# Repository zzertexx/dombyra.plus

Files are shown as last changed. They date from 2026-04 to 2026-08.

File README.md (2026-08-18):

# Dombyra Plus
Simple device to teach playing on Dombyra!


## Description
Have you ever wanted to learn playing Dombyra at home?
If yes, then you absolutely looked resources to learn, and what you found was some videos that shows you how they play, while you need to everytime find out which notes is being pressed.

I had exact same problem, so I built this!

This device is solution for it. First hardware addon for Dombyra.

Using bunch of SK6812 LEDs on Dombyra's neck, it will show you which notes need to be pressed right now and after.
By ESP32 and INMP441 mic, it will be controlled by local Website to choose notes and continue showing notes.

## Features
* Wi-Fi website to choose kuis
* 18 LEDs per string with two color mod for Up/Down play
* Battery charge system for autonomuos play
* Comfortable case to play
* Volume spike detector to continue play

## Firmware
* Firmware was written on Arduino IDE
* Currently it has Erkem-Ai
* Needed libraries: FastLED.h, i2s.h(core), WiFi.h(core), WebServer.h(core)

## Attachment
To make sure cases won't move, I added attachment legs for **LED case** and also usage of nylon tape for **microphone case** so you can remove device whenever you want

## How to actually use it?
1) Assemble PCB into Case
2) Use nylon to attach microphone case
3) Compile code into ESP32
4) Place PCBs on dombyra and connect both using **4-pin JST XH2.54** and specialized pins
5) Charge battery and start it
6) Connect to ESP32's Wi-Fi and enter http://192.168.4.1
7) Choose the kui that you wanna learn and enjoy the process!

## Bill of Materials

| Component | Quantity |
|---|---|
| ESP32 DevKit v1 | 1 |
| SK6812 LEDs | 38 |
| INMP441 module | 1 |
| Li-Po Battery + 2 pin header 2mm | 1 |
| USB-C Receptacle only 6 pin | 1 |
| TP4056 module | 1 |
| MT3608 module | 1 |
| M2 screws | 14 |
| M3 screws | 4 |
| 4 pin Connector Sockets - Angled | 1 |
| 4 pin Connector Sockets - Vertical | 1 |
| NTC 10k | 1 |
| Unpolarized capacitors(THT) 10uF & 22uF | 2 each |
| Inductor 4.7uH | 1 |
| Diode | 2 LED and 1 Schottky |
| Resistors | 110k; 15k; 330 x2; 68k; 2.4k; 1k; 0.4; 5k1 x2 |
| 4-pin JST XH2.54 | 1 |
| Nylon Tape | 1 |

## PCB & Schematics
Designed on KiCad 10.0

It consists of 2 PCBs. One on neck for LEDs and second one for Battery, Microphone and MCU. They are connected using 4-pin JST wires for GND, 5V and 2 data channels. 






## Images of cases
dombyra_case
3D Case2
3D Case1

## Demo 

https://youtu.be/3Eh5J_6kmjc

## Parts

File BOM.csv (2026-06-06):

Name | Quantity | Price | Link
SK6812 5050 | 38 | 6.33$/50pcs | https://aliexpress.ru/item/33015141472.html?sku_id=67232448537
4 pin Connector Sockets - angled | 1 | 0.76$/10pcs | https://aliexpress.ru/item/1005008048770666.html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
4 pin Connector Sockets - vertical | 1 | 0.64$/40pcs | https://aliexpress.ru/item/1005008048770666.html?mixer_rcmd_bucket_id=eb9dde40e7725560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
INMP441 module | 1 | 0.84$ | https://aliexpress.ru/item/1005004862555297.html?sku_id=12000030790772841
Li Po 1000 mAh | 1 | 5.82$ | https://aliexpress.ru/item/1005003380188983.html?sku_id=12000032368701982
2-Pin Header 2mm | 1 | 0.31$ | https://aliexpress.ru/item/1005004613948731.html?sku_id=12000029835450870
USB-C Receptacle only 6 pin | 1 | 0.93$ | https://aliexpress.ru/item/1005008515699009.html?sku_id=12000045521870266
ESP32 DevKit v1 | 1 | 3.68$ | https://aliexpress.ru/item/1005008819591380.html?sku_id=12000052999823660
TP4056 | 1 | 0.2$ | https://aliexpress.ru/item/1005001848329482.html?sku_id=12000046271485575
NTC 10k | 1 | 0.53$ / 10pcs | https://aliexpress.ru/item/1005004726168052.html?sku_id=12000056723062683
Unpolarized capacitor(THT) 10uF | 2 | 0.97$ / 40pcs | https://aliexpress.ru/item/1005011811368397.html?sku_id=12000056639843396
Unpolarized capacitor(THT) 22uF | 2 | 0.97$ / 40pcs | https://aliexpress.ru/item/1005011811368397.html?sku_id=12000056639843396
MT3608 | 1 | 1.38$ / 10pcs | https://aliexpress.ru/item/1005008853748359.html?sku_id=12000046953414150
Inductor 4.7uH | 1 | 0.54$ / 10pcs | https://aliexpress.ru/item/1005001705755960.html?sku_id=12000017231427125
LED Diode | 2 | 0.78$ / 60 pcs | https://aliexpress.ru/item/1005006462860778.html?sku_id=12000037284612047
Schottky diode | 1 | 0.88$ / 50pcs | https://aliexpress.ru/item/1005005913997312.html?sku_id=12000034823544465
Resistor 110k | 1 | 0.4$ / 100pcs | https://aliexpress.ru/item/1005005305821597.html?sku_id=12000032565737692
Resistor 15K | 1 | 0.46$ / 100pcs | https://aliexpress.ru/item/1005010583226050.html?mixer_rcmd_bucket_id=eb9dde40e7725560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
Resistor 330 | 2 | 0.46$ / 100pcs | https://aliexpress.ru/item/1005010583226050.html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
Resistor 68k | 1 | 0.46$ / 100pcs | https://aliexpress.ru/item/1005010583226050.html?mixer_rcmd_bucket_id=eb9dde40e7725560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
Resistor 2.4k | 1 | 0.46$ / 100pcs | https://aliexpress.ru/item/1005010583226050.html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
Resistor 1k | 1 | 0.46$ / 100pcs | https://aliexpress.ru/item/1005010583226050.html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
Resistor 0.4 | 1 | 0.46$ / 100pcs | https://aliexpress.ru/item/1005010583226050.html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
Resistor 5.1k | 2 | 0.46$ / 100pcs | https://aliexpress.ru/item/1005010583226050.html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
4-pin JST XH2.54 | 1 | 1.12$ | https://aliexpress.ru/item/1005004837211340.html?sku_id=12000030681544733
Nylon Tape | 1 | 0.87$ | https://aliexpress.ru/item/1005004816765023.html?sku_id=12000030600334971
Effective Sum |  | 19.5$/pc
Sum |  | 31$

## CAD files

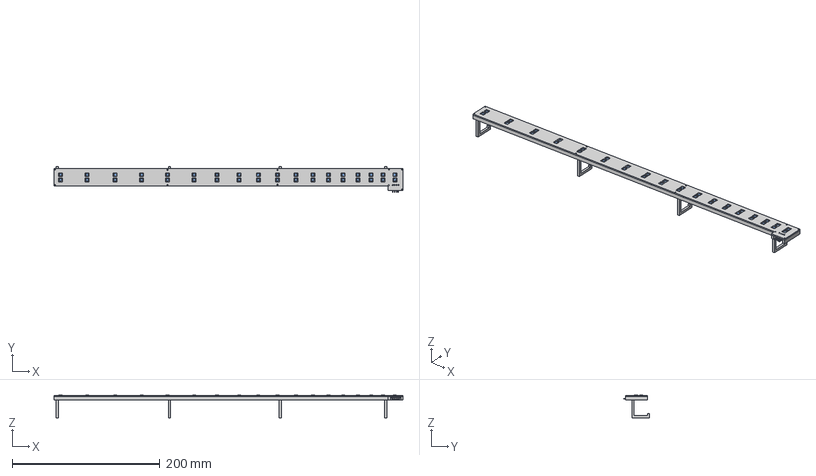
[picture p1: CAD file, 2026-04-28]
CAD/dombyra_case.step
472.9 x 35.2 x 30.6 mm

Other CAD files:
CAD/dombyra_case.f3z

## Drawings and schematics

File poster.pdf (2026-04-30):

# Dombyra+

# SK6812 LEDs going to

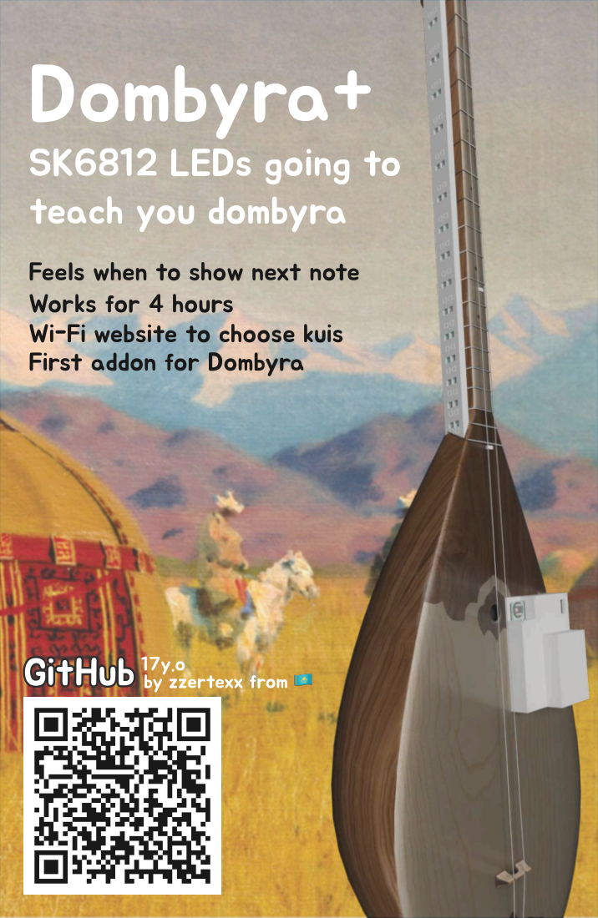
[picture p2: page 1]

teach you dombyra

Feels when to show next note
Works for 4 hours
Wi-Fi website to choose kuis
First addon for Dombyra

GitHub ¹⁷y.o by zzertexx from 🇰🇿

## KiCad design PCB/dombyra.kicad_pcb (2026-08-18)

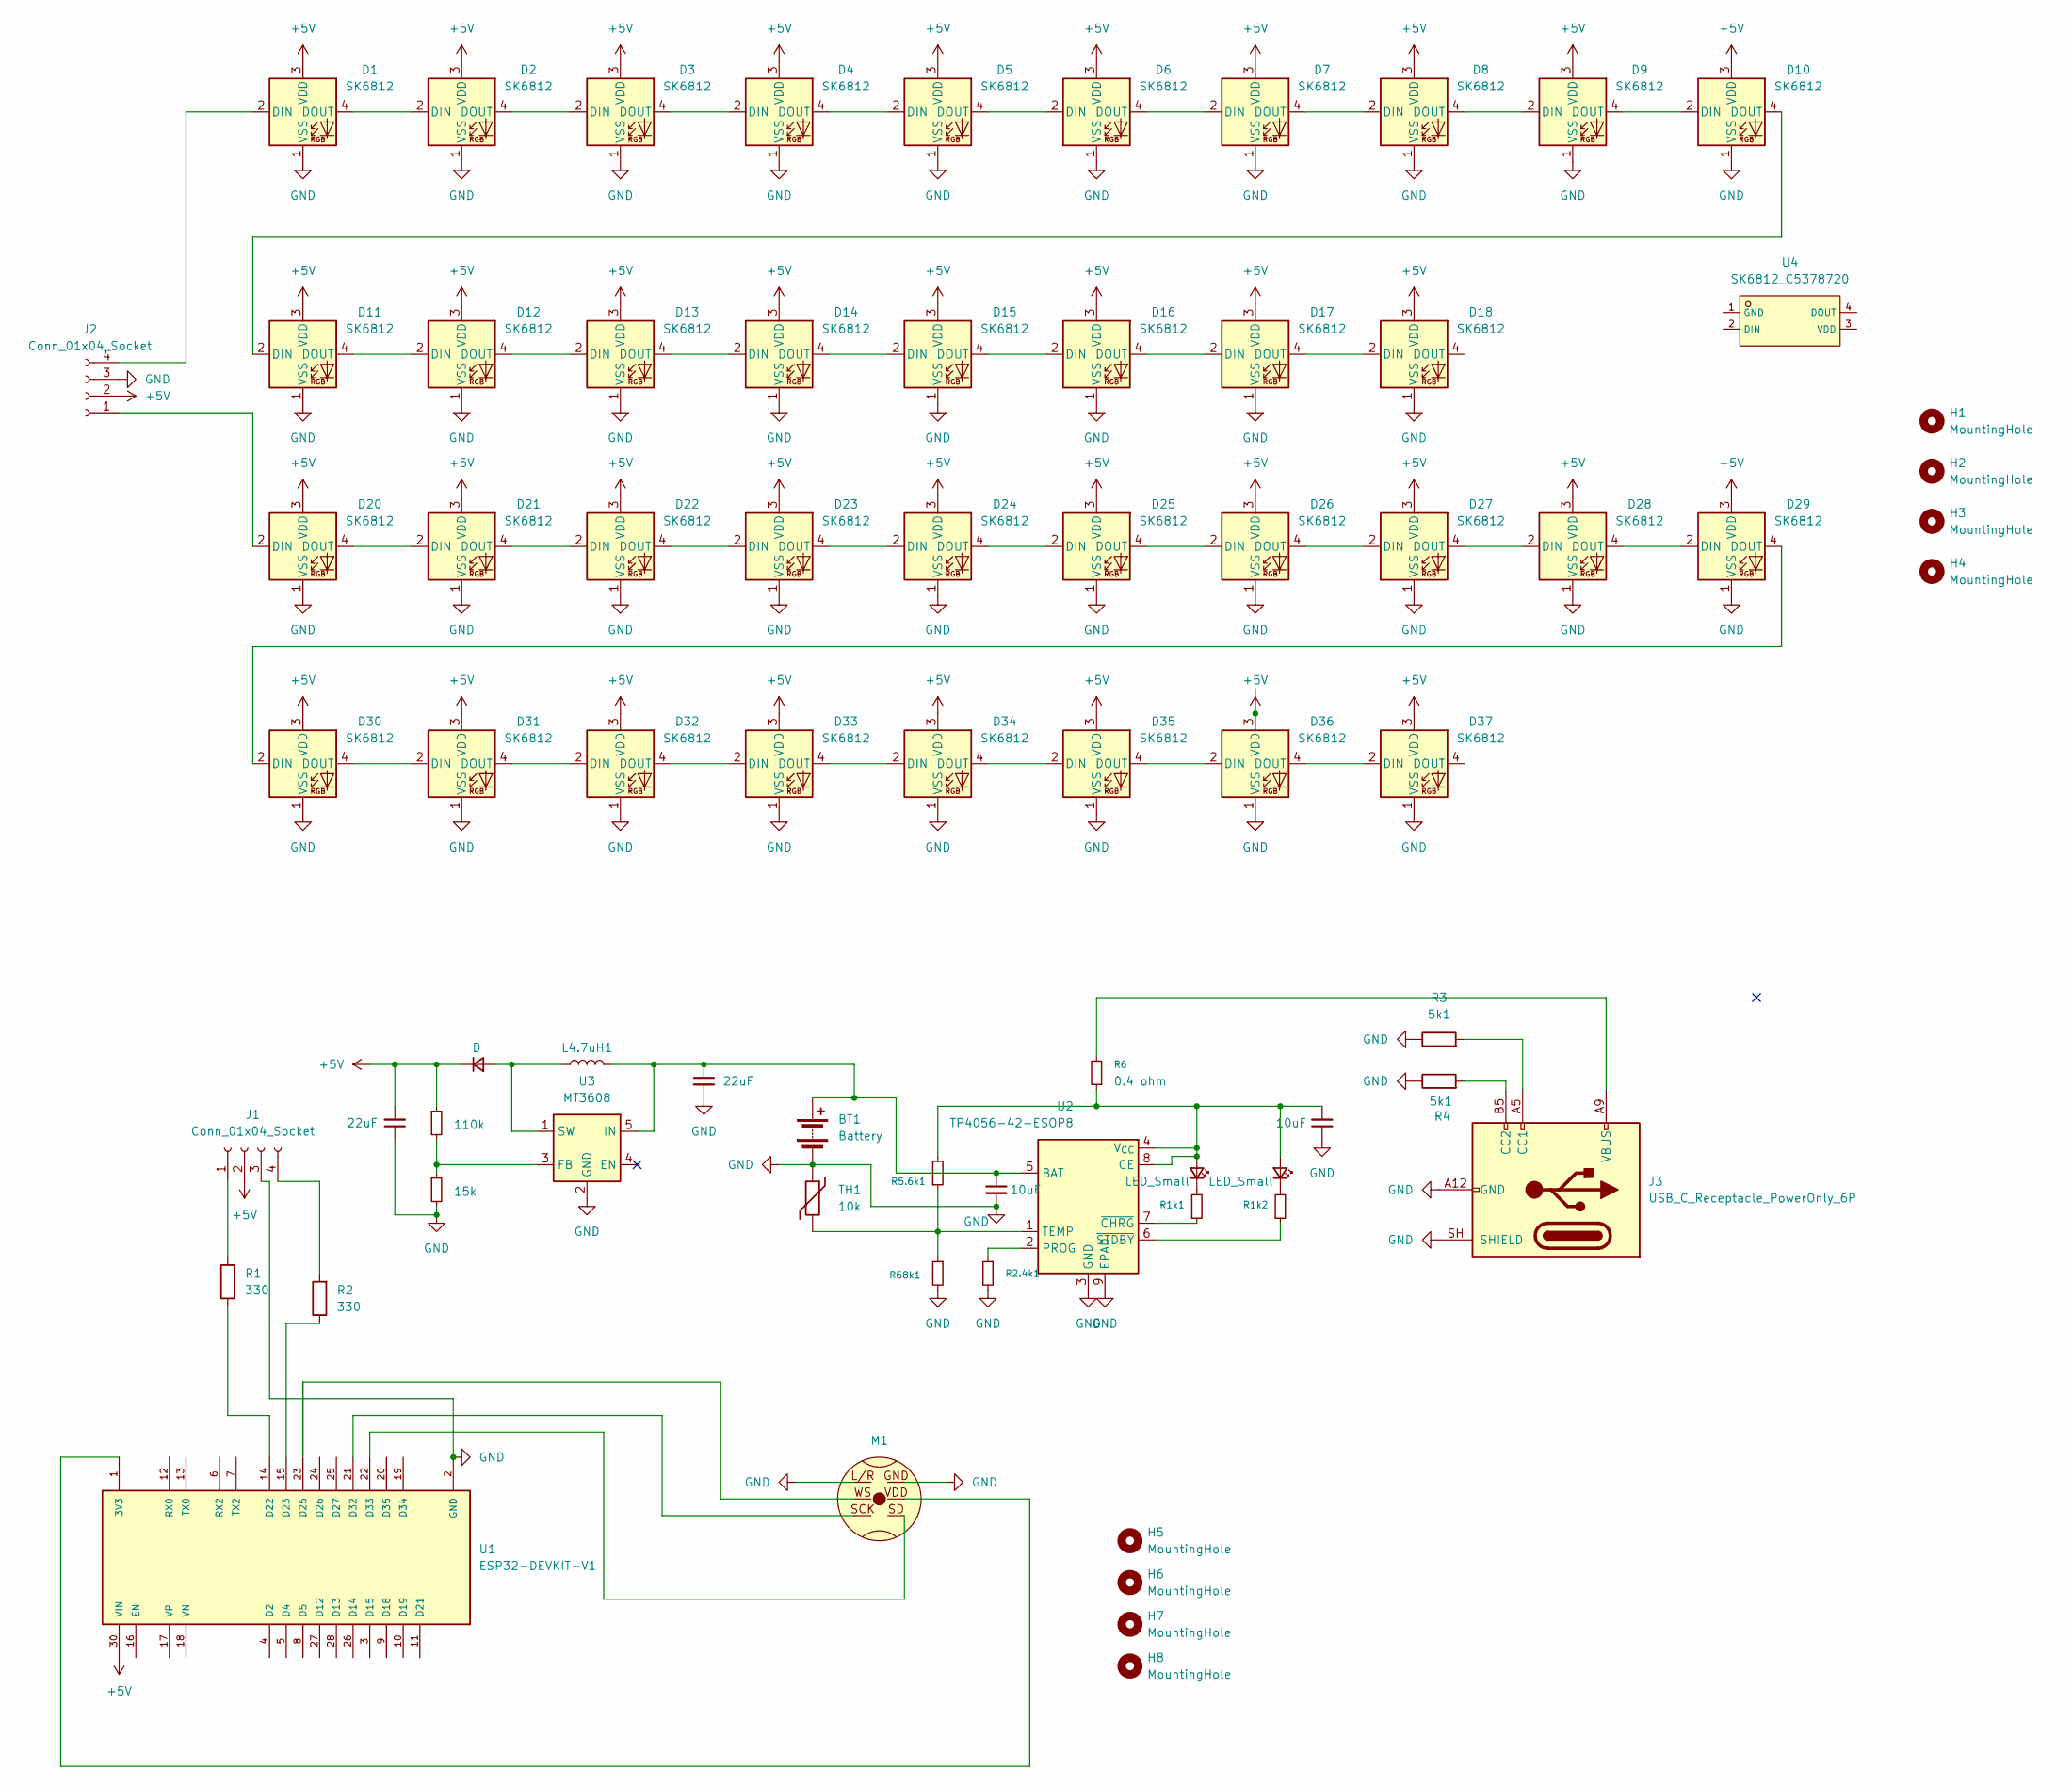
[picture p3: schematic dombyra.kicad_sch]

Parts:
BT1: Battery; PinHeader_1x02_P2.54mm_Vertical
C1, C2: 10uF; C_0805_2012Metric
C3, C4: 22uF; C_1206_3216Metric
D1, D2, D3, D4, D5, D6, D7, D8, D9, D10, D11, D12, D13, D14, D15, D16, D17, D18, D20, D21, D22, D23, D24, D25, D26, D27, D28, D29, D30, D31, D32, D33, D34, D35, D36, D37: SK6812; LED_SK6812_PLCC4_5.0x5.0mm_P3.2mm
D39: LED_Small; LED_D3.0mm
D40: LED_Small; LED_D5.0mm
D41: D; SMA_L4.3-W2.6-LS5.2-RD
H1, H2, H3, H4: MountingHole; MountingHole_3.2mm_M3
H5, H6, H7, H8: MountingHole; MountingHole_2.2mm_M2
J1: Conn_01x04_Socket; PinHeader_1x04_P2.54mm_Vertical_SMD_Pin1Left
J2: Conn_01x04_Socket; PinHeader_1x04_P2.54mm_Horizontal
J3: USB_C_Receptacle_PowerOnly_6P; USB_C_Receptacle_GCT_USB4135-GF-A_6P_TopMnt_Horizontal
L4.7uH1: L; L_1812_4532Metric
M1: INMP441
R1, R2: 330; R_0402_1005Metric
R1k1, R1k2: R_Small; R_0805_2012Metric
R2.4k1: R_Small; R_Axial_DIN0204_L3.6mm_D1.6mm_P1.90mm_Vertical
R3, R4: 5k1; R_0603_1608Metric
R5.6k1, R68k1: R_Small; R_0603_1608Metric
R6: 0.4 ohm; R_Axial_DIN0204_L3.6mm_D1.6mm_P1.90mm_Vertical
R9: 15k; R_0402_1005Metric
R10: 110k; R_0603_1608Metric
TH1: 10k; PinHeader_2x01_P2.00mm_Vertical
U1: ESP32-DEVKIT-V1; MODULE_ESP32_DEVKIT_V1; PARTREV N/A
U2: TP4056-42-ESOP8; SOIC-8-1EP_3.9x4.9mm_P1.27mm_EP2.41x3.3mm_ThermalVias
U3: MT3608; SOT-23-6
U4: SK6812_C5378720; LED-SMD_4P-L5.4-W5.0_SK6812; LCSC C5378720

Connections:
+5V: C3.2, D1.3 (VDD), D2.3 (VDD), D3.3 (VDD), D4.3 (VDD), D5.3 (VDD), D6.3 (VDD), D7.3 (VDD), D8.3 (VDD), D9.3 (VDD), D10.3 (VDD), D11.3 (VDD), D12.3 (VDD), D13.3 (VDD), D14.3 (VDD), D15.3 (VDD), D16.3 (VDD), D17.3 (VDD), D18.3 (VDD), D20.3 (VDD), D21.3 (VDD), D22.3 (VDD), D23.3 (VDD), D24.3 (VDD), D25.3 (VDD), D26.3 (VDD), D27.3 (VDD), D28.3 (VDD), D29.3 (VDD), D30.3 (VDD), D31.3 (VDD), D32.3 (VDD), D33.3 (VDD), D34.3 (VDD), D35.3 (VDD), D36.3 (VDD), D37.3 (VDD), D41.1 (K), J1.2, J2.2, R10.1, U1.30 (VIN)
GND: BT1.2 (-), C1.2, C2.1, C3.1, C4.2, D1.1 (VSS), D2.1 (VSS), D3.1 (VSS), D4.1 (VSS), D5.1 (VSS), D6.1 (VSS), D7.1 (VSS), D8.1 (VSS), D9.1 (VSS), D10.1 (VSS), D11.1 (VSS), D12.1 (VSS), D13.1 (VSS), D14.1 (VSS), D15.1 (VSS), D16.1 (VSS), D17.1 (VSS), D18.1 (VSS), D20.1 (VSS), D21.1 (VSS), D22.1 (VSS), D23.1 (VSS), D24.1 (VSS), D25.1 (VSS), D26.1 (VSS), D27.1 (VSS), D28.1 (VSS), D29.1 (VSS), D30.1 (VSS), D31.1 (VSS), D32.1 (VSS), D33.1 (VSS), D34.1 (VSS), D35.1 (VSS), D36.1 (VSS), D37.1 (VSS), J1.3, J2.3, J3.A12 (GND), J3.B12 (GND), J3.SH (SHIELD), M1.GND, M1.L/R, R2.4k1.2, R3.1, R4.1, R9.2, R68k1.2, TH1.1, U1.2 (GND), U1.29 (GND), U2.3 (GND), U2.9 (EPAD), U3.2 (GND)
unnamed: BT1.1 (+), C1.1, C4.1, L4.7uH1.2, U2.5 (BAT), U3.5 (IN)
unnamed: D1.2 (DIN), J2.4
unnamed: D1.4 (DOUT), D2.2 (DIN)
unnamed: D2.4 (DOUT), D3.2 (DIN)
unnamed: D3.4 (DOUT), D4.2 (DIN)
unnamed: D4.4 (DOUT), D5.2 (DIN)
unnamed: D5.4 (DOUT), D6.2 (DIN)
unnamed: D6.4 (DOUT), D7.2 (DIN)
unnamed: D7.4 (DOUT), D8.2 (DIN)
unnamed: D8.4 (DOUT), D9.2 (DIN)
unnamed: D9.4 (DOUT), D10.2 (DIN)
unnamed: D10.4 (DOUT), D11.2 (DIN)
unnamed: D11.4 (DOUT), D12.2 (DIN)
unnamed: D12.4 (DOUT), D13.2 (DIN)
unnamed: D13.4 (DOUT), D14.2 (DIN)
unnamed: D14.4 (DOUT), D15.2 (DIN)
unnamed: D15.4 (DOUT), D16.2 (DIN)
unnamed: D16.4 (DOUT), D17.2 (DIN)
unnamed: D17.4 (DOUT), D18.2 (DIN)
unnamed: D20.2 (DIN), J2.1
unnamed: D20.4 (DOUT), D21.2 (DIN)
unnamed: D21.4 (DOUT), D22.2 (DIN)
unnamed: D22.4 (DOUT), D23.2 (DIN)
unnamed: D23.4 (DOUT), D24.2 (DIN)
unnamed: D24.4 (DOUT), D25.2 (DIN)
unnamed: D25.4 (DOUT), D26.2 (DIN)
unnamed: D26.4 (DOUT), D27.2 (DIN)
unnamed: D27.4 (DOUT), D28.2 (DIN)
unnamed: D28.4 (DOUT), D29.2 (DIN)
unnamed: D29.4 (DOUT), D30.2 (DIN)
unnamed: D30.4 (DOUT), D31.2 (DIN)
unnamed: D31.4 (DOUT), D32.2 (DIN)
unnamed: D32.4 (DOUT), D33.2 (DIN)
unnamed: D33.4 (DOUT), D34.2 (DIN)
unnamed: D34.4 (DOUT), D35.2 (DIN)
unnamed: D35.4 (DOUT), D36.2 (DIN)
unnamed: D36.4 (DOUT), D37.2 (DIN)
unnamed: C2.2, D39.2 (A), D40.2 (A), R5.6k1.2, R6.1, U2.4 (V_{CC}), U2.8 (CE)
unnamed: D39.1 (K), R1k1.2
unnamed: D40.1 (K), R1k2.2
unnamed: D41.2 (A), L4.7uH1.1, U3.1 (SW)
unnamed: J1.1, R1.2
unnamed: J1.4, R2.2
unnamed: J3.A5 (CC1), R3.2
unnamed: J3.B5 (CC2), R4.2
unnamed: J3.A9 (VBUS), J3.B9 (VBUS), R6.2
unnamed: M1.VDD, U1.1 (3V3)
unnamed: R1.1, U1.14 (D22)
unnamed: R2.1, U1.15 (D23)
unnamed: M1.WS, U1.23 (D25)
unnamed: M1.SCK, U1.21 (D32)
unnamed: M1.SD, U1.22 (D33)
unnamed: R2.4k1.1, U2.2 (PROG)
unnamed: R5.6k1.1, R68k1.1, TH1.2, U2.1 (TEMP)
unnamed: R1k1.1, U2.7 (~CHRG)
unnamed: R1k2.1, U2.6 (~STDBY)
unnamed: R9.1, R10.2, U3.3 (FB)

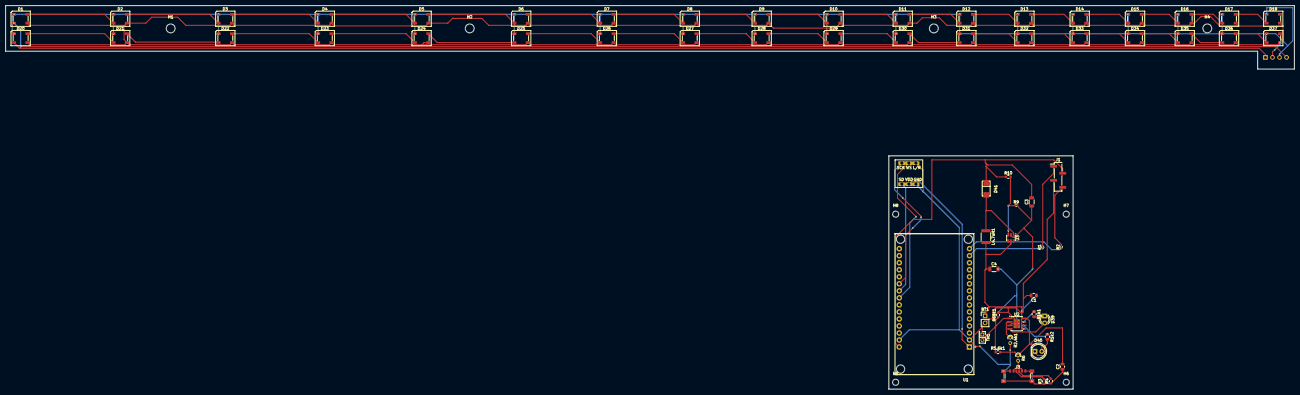
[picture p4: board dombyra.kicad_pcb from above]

Board: 2 copper layers, 466.1 x 138.7 mm, 73 parts (1 on the bottom side), 59 nets.

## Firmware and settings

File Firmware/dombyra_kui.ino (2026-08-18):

#include <WiFi.h>
#include <WebServer.h>
#include <ESPmDNS.h>
#include <FastLED.h>

#include "song.h"
#include "webpage.h"


#define PIN_S1        18
#define PIN_S2        19
#define LEDS_PER_STR  18           

#define S1_REVERSED   false
#define S2_REVERSED   false


#define LED_CHIPSET   SK6812
#define COLOR_ORDER   GRB

const char* AP_SSID = "DOMBYRA";
const char* AP_PASS = "dombyra123";     

const CRGB COL_S1     = CRGB(255, 120,  20);   
const CRGB COL_S2     = CRGB( 20, 200, 190);   
const CRGB COL_OPEN   = CRGB(255,   0,   0);   
const uint8_t PREVIEW_SCALE = 26;              
const uint8_t OPEN_SCALE    = 22;              
const uint8_t IDLE_SCALE    = 70;              

CRGB leds1[LEDS_PER_STR];
CRGB leds2[LEDS_PER_STR];
WebServer server(80);

enum Mode : uint8_t { MODE_AUTO = 0, MODE_MIC = 1 };

bool     playing   = false;
Mode     mode      = MODE_AUTO;
uint16_t idx       = 0;             
uint16_t bpm       = 120;
uint8_t  bright    = 70;
bool     loopSong  = true;
uint32_t noteStart = 0;
bool     dirty     = true;

inline uint32_t eighthMs() { return 30000UL / bpm; }   


inline uint8_t ledIndex(uint8_t fret, bool reversed) {
  uint8_t i = fret - 1;                       
  return reversed ? (LEDS_PER_STR - 1 - i) : i;
}

void paintString(CRGB* leds, bool reversed, int8_t fret, CRGB color, uint8_t scale) {
  if (fret < 0) return;                      
  if (fret == 0) {                            
    CRGB c = COL_OPEN;
    c.nscale8(scale8(OPEN_SCALE, scale));
    for (uint8_t i = 0; i < LEDS_PER_STR; i++) leds[i] += c;
    return;
  }
  if (fret > LEDS_PER_STR) return;           
  CRGB c = color;
  c.nscale8(scale);
  leds[ledIndex(fret, reversed)] = c;
}

void render() {
  fill_solid(leds1, LEDS_PER_STR, CRGB::Black);
  fill_solid(leds2, LEDS_PER_STR, CRGB::Black);

  Note cur = noteAt(idx);


  if (idx + 1 < songLength()) {
    Note nx = noteAt(idx + 1);
    paintString(leds1, S1_REVERSED, nx.s1, COL_S1, PREVIEW_SCALE);
    paintString(leds2, S2_REVERSED, nx.s2, COL_S2, PREVIEW_SCALE);
  }

  uint8_t s = playing ? 255 : IDLE_SCALE;
  paintString(leds1, S1_REVERSED, cur.s1, COL_S1, s);
  paintString(leds2, S2_REVERSED, cur.s2, COL_S2, s);

  FastLED.show();
}

void bootSweep() {
  for (uint8_t i = 0; i < LEDS_PER_STR; i++) {
    fill_solid(leds1, LEDS_PER_STR, CRGB::Black);
    fill_solid(leds2, LEDS_PER_STR, CRGB::Black);
    leds1[i] = COL_S1;
    leds2[LEDS_PER_STR - 1 - i] = COL_S2;
    FastLED.show();
    delay(25);
  }
}

void advance() {
  idx++;
  if (idx >= songLength()) {
    if (loopSong) {
      idx = 0;
    } else {
      idx = songLength() - 1;
      playing = false;
    }
  }
  noteStart = millis();
  dirty = true;
}

void restart() {
  idx = 0;
  noteStart = millis();
  dirty = true;
}

// ----------------------------------------------------------------- HTTP ---
void sendState() {
  Note cur = noteAt(idx);

  char n1[8] = "null", n2[8] = "null";
  if (idx + 1 < songLength()) {
    Note nx = noteAt(idx + 1);
    snprintf(n1, sizeof(n1), "%d", nx.s1);
    snprintf(n2, sizeof(n2), "%d", nx.s2);
  }

  char json[240];
  snprintf(json, sizeof(json),
    "{\"playing\":%s,\"mode\":%u,\"bpm\":%u,\"bright\":%u,"
    "\"idx\":%u,\"total\":%u,\"bar\":%u,\"bars\":%u,"
    "\"s1\":%d,\"s2\":%d,\"dir\":%u,\"n1\":%s,\"n2\":%s}",
    playing ? "true" : "false", (unsigned)mode, bpm, bright,
    idx, songLength(), cur.bar, (unsigned)(PART_BARS * SECTION_REPEATS),
    cur.s1, cur.s2, (unsigned)cur.dir, n1, n2);

  server.sendHeader("Cache-Control", "no-store");
  server.send(200, "application/json", json);
}

void handleCmd() {
  String c = server.arg("c");
  long   v = server.arg("v").toInt();

  if (c == "start") {
    playing   = true;
    noteStart = millis();
  } else if (c == "stop") {
    playing = false;
  } else if (c == "restart") {
    restart();
    playing = true;
    noteStart = millis();
  } else if (c == "next") {
    if (!playing) playing = true;
    advance();
  } else if (c == "prev") {
    idx = (idx == 0) ? songLength() - 1 : idx - 1;
    noteStart = millis();
  } else if (c == "mode") {
    mode = (v == 1) ? MODE_MIC : MODE_AUTO;
    noteStart = millis();
  } else if (c == "bpm") {
    bpm = constrain(v, 40, 200);
  } else if (c == "bright") {
    bright = constrain(v, 5, 255);
    FastLED.setBrightness(bright);
  } else if (c == "loop") {
    loopSong = (v != 0);
  }
  dirty = true;
  sendState();
}

void setup() {
  Serial.begin(115200);

  FastLED.addLeds<LED_CHIPSET, PIN_S1, COLOR_ORDER>(leds1, LEDS_PER_STR);
  FastLED.addLeds<LED_CHIPSET, PIN_S2, COLOR_ORDER>(leds2, LEDS_PER_STR);
  FastLED.setBrightness(bright);
  FastLED.setMaxPowerInVoltsAndMilliamps(5, 1500);   
  bootSweep();

  WiFi.mode(WIFI_AP);
  WiFi.softAP(AP_SSID, AP_PASS);
  Serial.printf("AP \"%s\"  ->  http://%s\n",
                AP_SSID, WiFi.softAPIP().toString().c_str());
  if (MDNS.begin("dombyra")) Serial.println("also http://dombyra.local");

  server.on("/", HTTP_GET, []() {
    server.sendHeader("Cache-Control", "no-store");
    server.send_P(200, "text/html", INDEX_HTML);
  });
  server.on("/api/state", HTTP_GET, sendState);
  server.on("/api/cmd",   HTTP_GET, handleCmd);
  server.onNotFound([]() { server.send(404, "text/plain", "404"); });
  server.begin();

  restart();
}

void loop() {
  server.handleClient();

  if (playing && mode == MODE_AUTO) {
    uint32_t due = (uint32_t)noteAt(idx).units * eighthMs();
    if (millis() - noteStart >= due) advance();
  }

  if (dirty) {
    dirty = false;
    render();
  }
}
